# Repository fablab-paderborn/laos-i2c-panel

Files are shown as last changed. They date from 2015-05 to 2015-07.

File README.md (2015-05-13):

# laos-i2c-panel
This is an rebuild of the LAOS I2C Panel v0.4, optimized for single-sided assembly and cnc milled production.

The original pcb is published at
  https://github.com/LaosLaser/AddOns/tree/master/i2c-panel/pcb-0.4
and designed with KiCAD.

This version is redesigned with EAGLE and optimized for milled production.

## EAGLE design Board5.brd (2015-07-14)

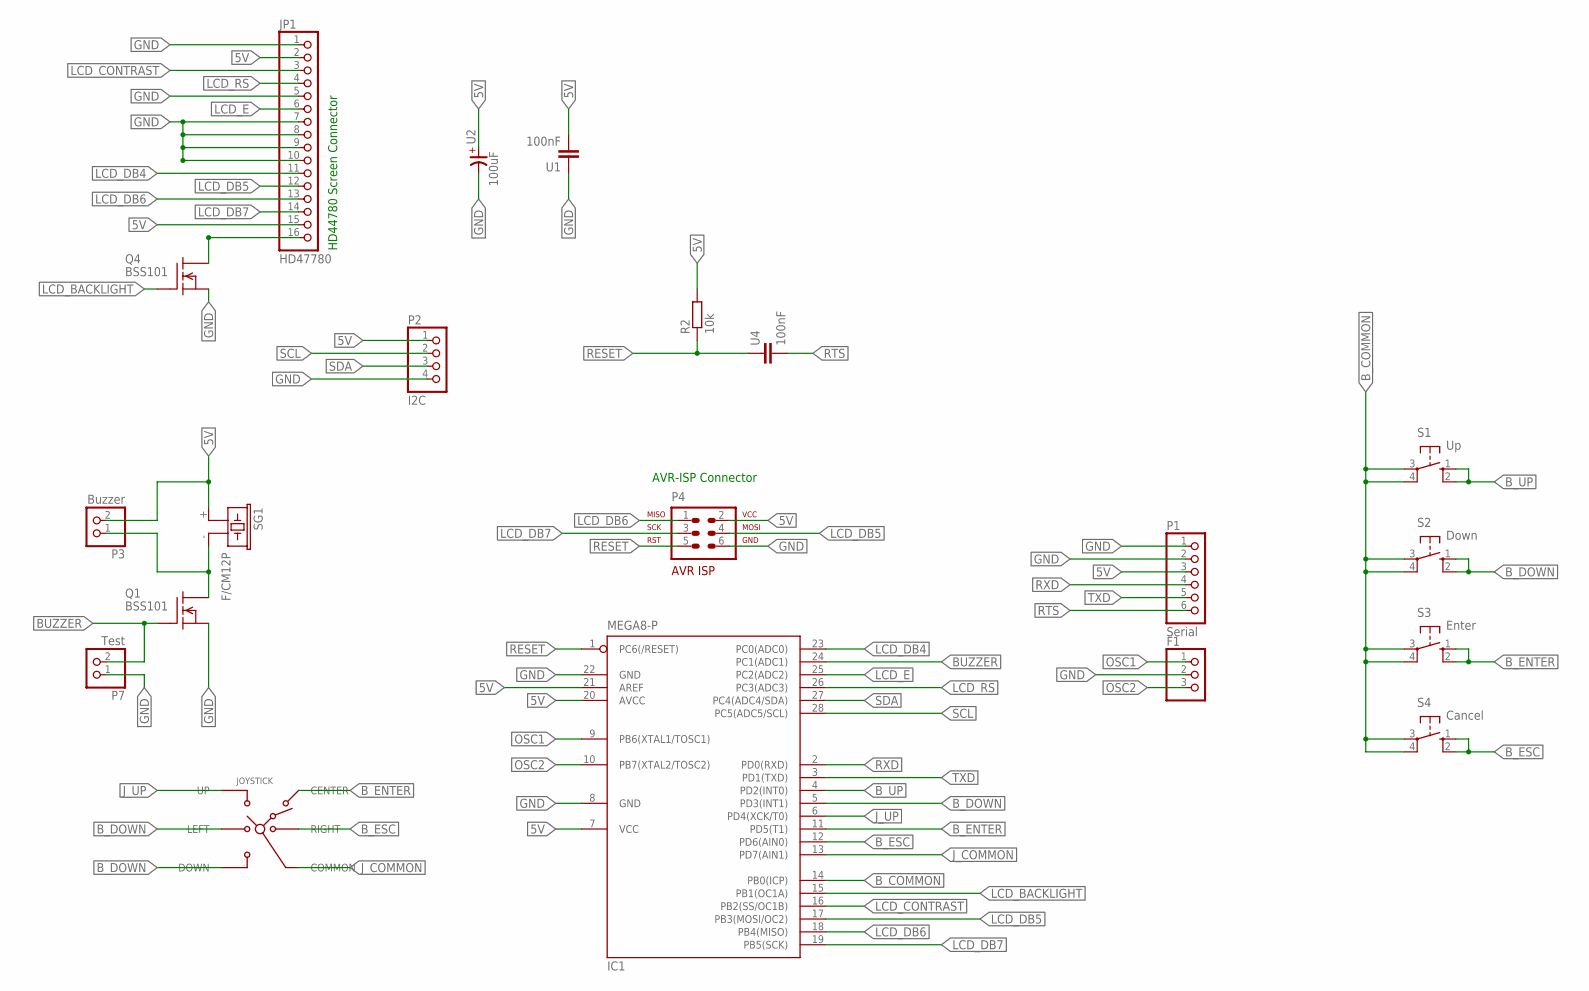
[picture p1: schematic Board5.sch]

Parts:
F1: PINHD-1X3; 1X03
IC1: MEGA8-P; DIL28-3
JOYSTICK: SKQUAAA010; SKQU
JP1: HD47780; 1X16
P1: Serial; 1X06
P2: I2C; 1X04
P3: Buzzer; 1X02
P4: ISP_WANNENBUCHSE; ML6
P7: Test; 1X02
Q1, Q4: BSS101; TO92
R2: 10k; 0207/10
S1: Up; B3F-40XX
S2: Down; B3F-40XX
S3: Enter; B3F-40XX
S4: Cancel; B3F-40XX
SG1: F/CM12P
U1, U4: 100nF; C050-024X044
U2: 100uF; E-020X050

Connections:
5V: IC1.7 (VCC), IC1.20 (AVCC), IC1.21 (AREF), JP1.2, JP1.15, P1.3, P2.1, P3.2, P4.2 (VCC), R2.2, SG1.+ (1), U1.2, U2.+
BUZZER: IC1.24 (PC1(ADC1)), P7.2, Q1.2 (G)
B_COMMON: IC1.14 (PB0(ICP)), S1.3, S1.4 (P1), S2.3, S2.4 (P1), S3.3, S3.4 (P1), S4.3, S4.4 (P1)
B_DOWN: IC1.5 (PD3(INT1)), JOYSTICK.DOWN, JOYSTICK.LEFT, S2.1 (S), S2.2 (S1)
B_ENTER: IC1.11 (PD5(T1)), JOYSTICK.CENTER, S3.1 (S), S3.2 (S1)
B_ESC: IC1.12 (PD6(AIN0)), JOYSTICK.RIGHT, S4.1 (S), S4.2 (S1)
B_UP: IC1.4 (PD2(INT0)), S1.1 (S), S1.2 (S1)
GND: F1.2, IC1.8 (GND), IC1.22 (GND), JP1.1, JP1.5, JP1.7, JP1.8, JP1.9, JP1.10, P1.1, P1.2, P2.4, P4.6 (GND), P7.1, Q1.1 (S), Q4.1 (S), U1.1, U2.-
J_COMMON: IC1.13 (PD7(AIN1)), JOYSTICK.COMMON
J_UP: IC1.6 (PD4(XCK/T0)), JOYSTICK.UP
LCD_BACKLIGHT: IC1.15 (PB1(OC1A)), Q4.2 (G)
LCD_CONTRAST: IC1.16 (PB2(SS/OC1B)), JP1.3
LCD_DB4: IC1.23 (PC0(ADC0)), JP1.11
LCD_DB5: IC1.17 (PB3(MOSI/OC2)), JP1.12, P4.4 (MOSI)
LCD_DB6: IC1.18 (PB4(MISO)), JP1.13, P4.1 (MISO)
LCD_DB7: IC1.19 (PB5(SCK)), JP1.14, P4.3 (SCK)
LCD_E: IC1.25 (PC2(ADC2)), JP1.6
LCD_RS: IC1.26 (PC3(ADC3)), JP1.4
unnamed: JP1.16, Q4.3 (D)
unnamed: P3.1, Q1.3 (D), SG1.- (2)
OSC1: F1.1, IC1.9 (PB6(XTAL1/TOSC1))
OSC2: F1.3, IC1.10 (PB7(XTAL2/TOSC2))
RESET: IC1.1 (PC6(/RESET)), P4.5 (RST), R2.1, U4.1
RTS: P1.6, U4.2
RXD: IC1.2 (PD0(RXD)), P1.4
SCL: IC1.28 (PC5(ADC5/SCL)), P2.2
SDA: IC1.27 (PC4(ADC4/SDA)), P2.3
TXD: IC1.3 (PD1(TXD)), P1.5

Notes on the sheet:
AVR-ISP Connector
HD44780 Screen Connector

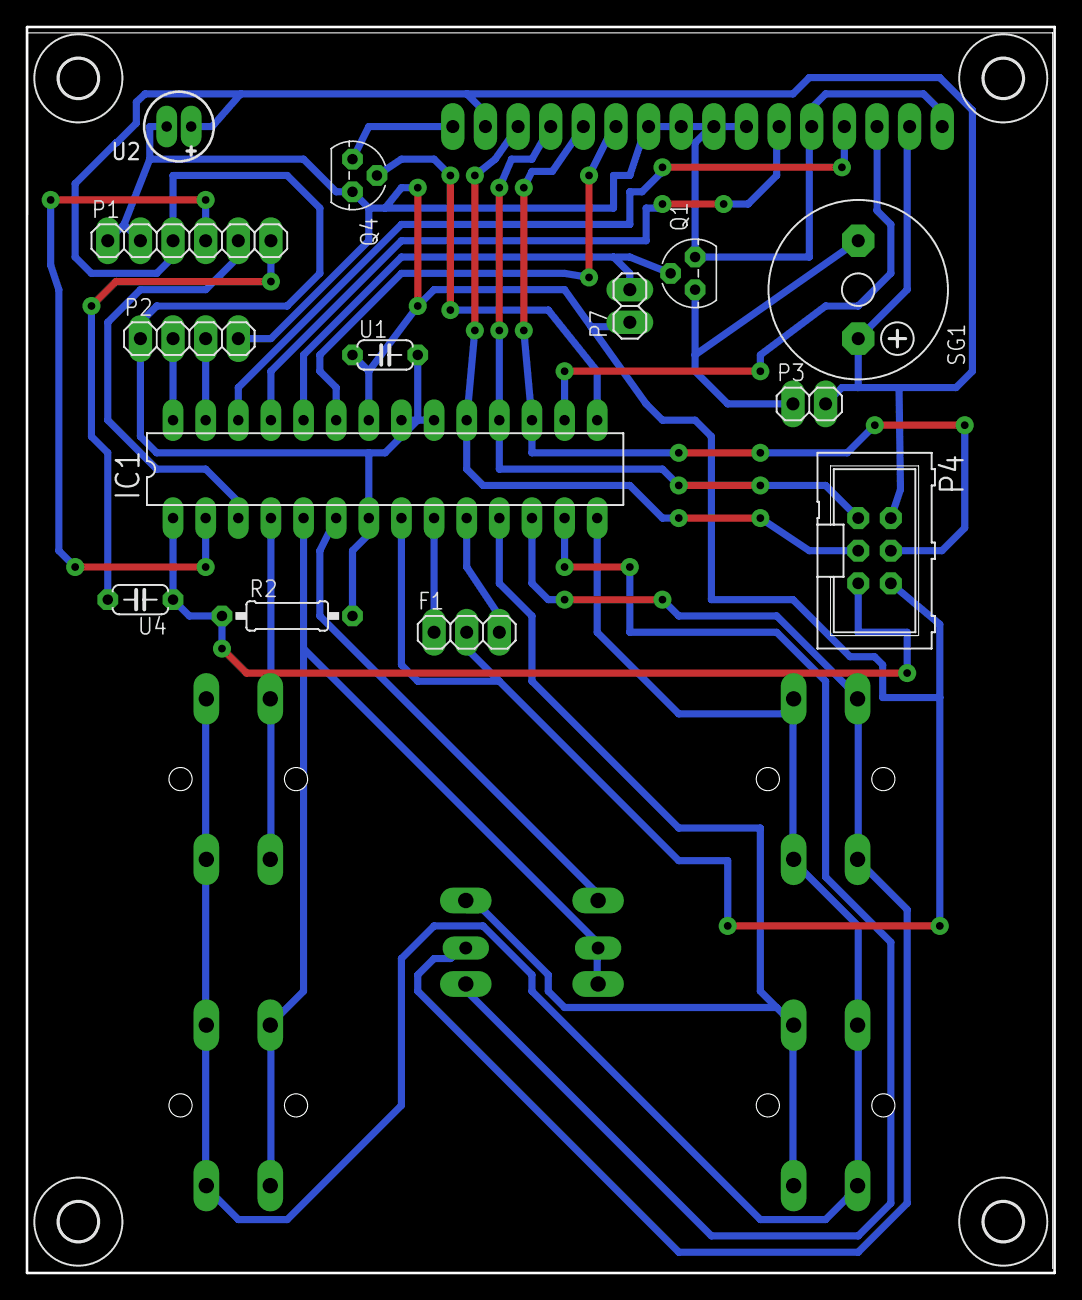
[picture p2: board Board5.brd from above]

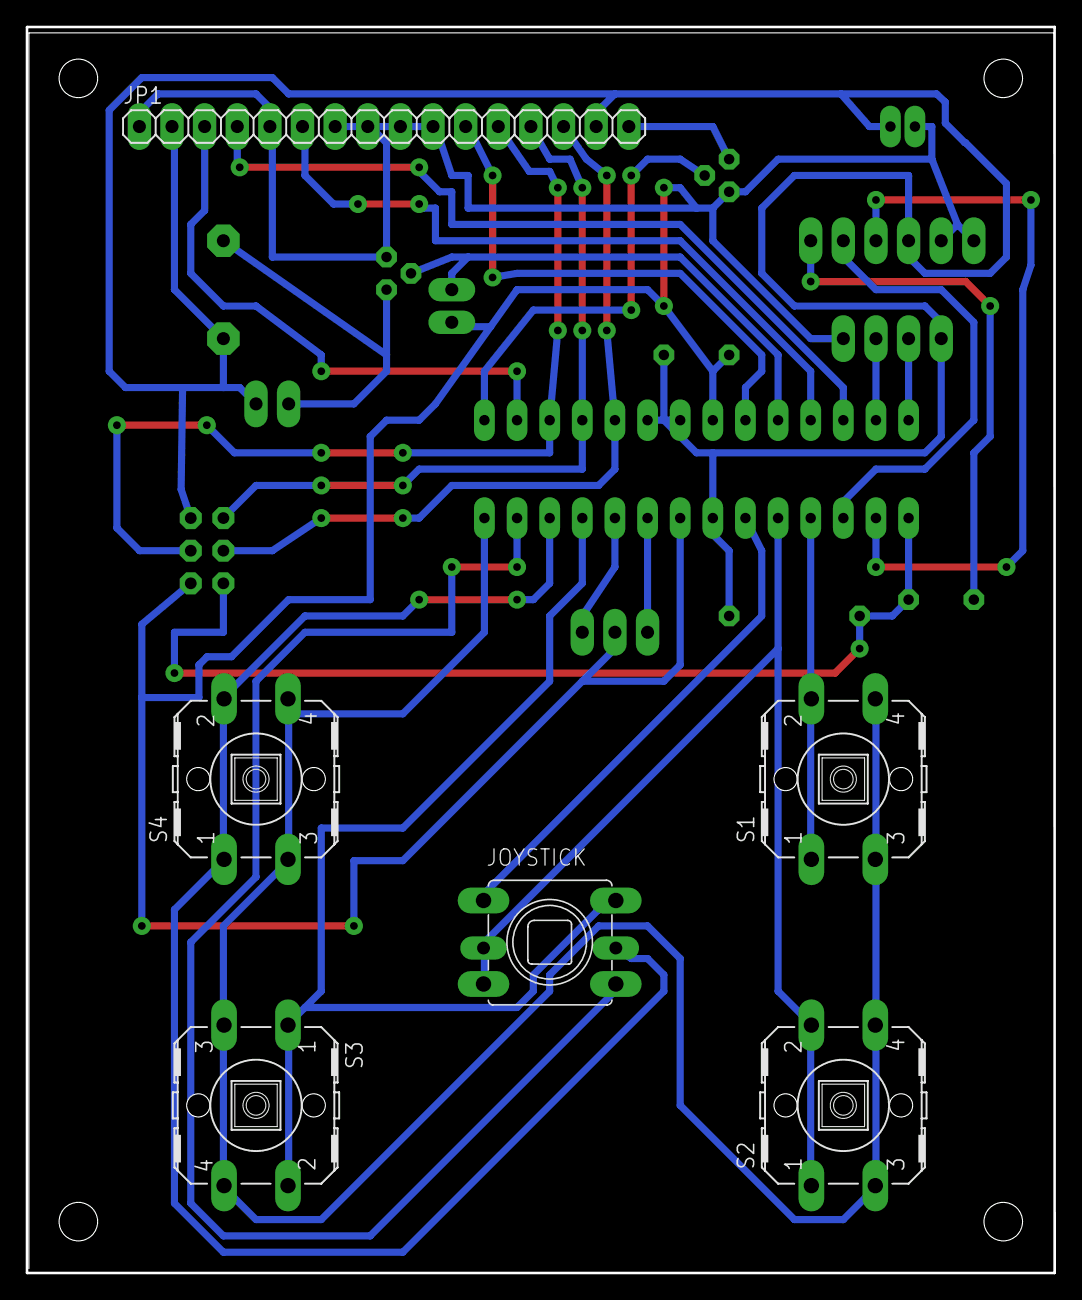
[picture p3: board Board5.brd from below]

Board: 2 copper layers, 80.0 x 97.0 mm, 24 parts (6 on the bottom side), 28 nets.

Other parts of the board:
U$1, U$2, U$3, U$4: 3,0

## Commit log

2015-05-18 Revision I
    [Board3.brd, Board3.sch]
2015-05-28 new revision with 16 mil clearance instead of 12 mil
    [Board4.brd, Board4.sch]
2015-05-28 bug in pcb fixed
    [Board4.brd]
2015-05-28 Top Print
2015-07-14 Board5: Extended Width
    [Board5.brd, Board5.sch]
2015-07-15 Mirrored and with Holes in the Pads
